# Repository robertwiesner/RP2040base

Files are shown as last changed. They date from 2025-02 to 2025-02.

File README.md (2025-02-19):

A small example for a RP2040 board with I2C (LCD display), LED blinking and some GPIOs

GPIO 0 - 3: LED

J4: 
GPIO6: GPIO/I2C1_SDA
GPIO7: GPIO/I2C1_SCL
GPIO8: GPIO/UART1_TX/I2C0_SDA/SPI1_RX
GPIO9: GPIO/UART1_RX/I2C0_SCL/SPI1_CSn
GPIO10: GPIO/I2C1_SDA/SPI1_SCK
GPIO11: GPIO/I2C1_SCL/SPI1_TX
GPIO12: GPIO/UART0_TX/I2C0_SDA/SPI1_RX
GPIO13: GPIO/UART0_RX/I2C0_SCL/SPI1_CSn

J3:
I2C0, GND, and 3.3V

HTTP Links and cloning:
* https://github.com/raspberrypi/picotool
* https://github.com/raspberrypi/pico-sdk
* https://github.com/raspberrypi/pico-extras

| End Symb |  |
| --- | --- |
| PICO_SDK_PATH | point to <path>/pico-sdk |
| PICO_EXTRAS_PATH | point to <path>/pico-extras |

Clone the pico repositories:
* https://github.com/raspberrypi/pico-sdk.git
* https://github.com/raspberrypi/pico-extras.git
* Install the picotool repository

How to build:
* First time:
 * make build directory in the source directory: mkdir build
 * chdir build
 * cmake ..
* every time
 * Change into build directory
 * Start build using "make"
 * install to pico: picotool load test.uf2 && picotool reboot

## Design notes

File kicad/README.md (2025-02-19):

This directory conteains the schematics and layout data for the C example program.

About the board:
1. Using a USB type C connector for power and USB 2.0 connection
2. I2C connector for LEC display
3. 4 * ANALOG input with 1:10 power divider for the RP2040 ADC input
4. Accessible GPIO 6 - 13
5. 2*5V (USB) and 2*3.3V connector
6. GPIO 0-3 connected to LED
7. 10-pin, 1.27mm SWD connector

The Part numbers in the schemetaics match the JLCPCB (not sponsered) order code.

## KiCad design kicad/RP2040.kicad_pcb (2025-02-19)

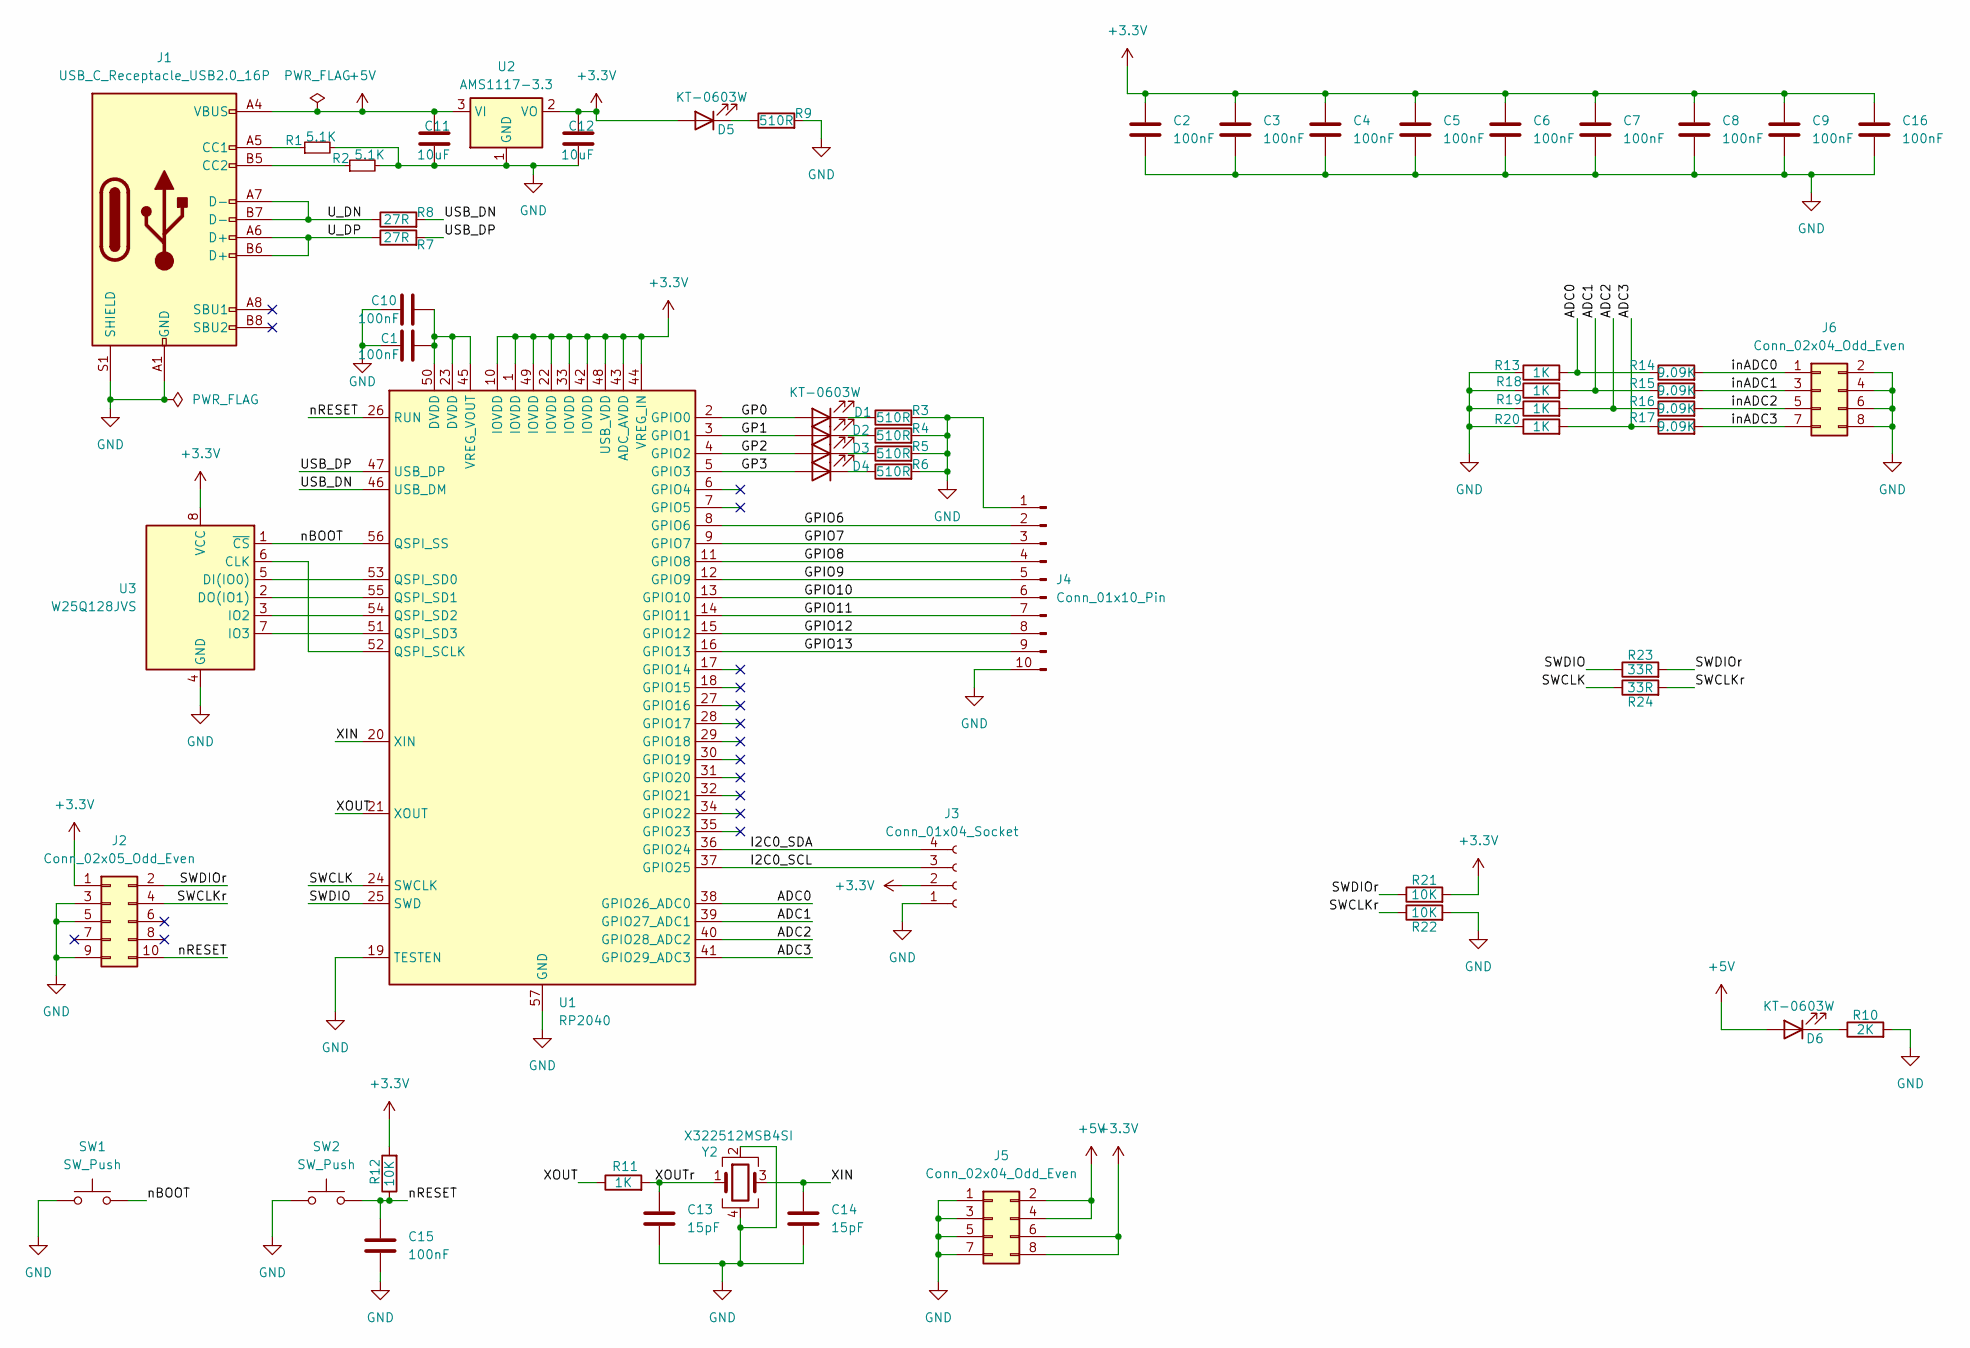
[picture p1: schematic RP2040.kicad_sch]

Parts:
C1, C2, C3, C4, C5, C6, C7, C8, C9, C10, C15, C16: 100nF; C_0402_1005Metric
C11, C12: 10uF; C_0603_1608Metric; LCSC C19702
C13, C14: 15pF; C_0402_1005Metric
D1, D2, D3, D4, D5, D6: KT-0603W; LED_0603_1608Metric
J1: USB_C_Receptacle_USB2.0_16P; USB_C_Receptacle_G-Switch_GT-USB-7010ASV
J2: Conn_02x05_Odd_Even; PinHeader_2x05_P1.27mm_Vertical_SMD; LCSC C5160761
J3: Conn_01x04_Socket; PinSocket_1x04_P2.54mm_Vertical
J4: Conn_01x10_Pin; PinSocket_1x10_P2.54mm_Vertical
J5, J6: Conn_02x04_Odd_Even; PinHeader_2x04_P2.54mm_Vertical
R1, R2: 5.1K; R_0402_1005Metric
R3, R4, R5, R6, R9: 510R; R_0402_1005Metric
R7, R8: 27R; R_0402_1005Metric
R10: 2K; R_0402_1005Metric
R11, R13, R18, R19, R20: 1K; R_0402_1005Metric
R12, R21, R22: 10K; R_0402_1005Metric
R14, R15, R16, R17: 9.09K; R_0402_1005Metric
R23, R24: 33R; R_0402_1005Metric
SW1, SW2: SW_Push; SW_Push_1P1T_XKB_TS-1187A
U1: RP2040; QFN-56-1EP_7x7mm_P0.4mm_EP3.2x3.2mm_ThermalVias
U2: AMS1117-3.3; SOT-223
U3: W25Q128JVS; SOIC-8_5.23x5.23mm_P1.27mm; LCSC C97521
Y2: X322512MSB4SI; Crystal_SMD_3225-4Pin_3.2x2.5mm; LCSC C9002

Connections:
+3.3V: C2.1, C3.1, C4.1, C5.1, C6.1, C7.1, C8.1, C9.1, C12.1, C16.1, D5.2 (A), J2.1, J3.2, J5.6, J5.8, R12.2, R21.2, U1.1 (IOVDD), U1.10 (IOVDD), U1.22 (IOVDD), U1.33 (IOVDD), U1.42 (IOVDD), U1.43 (ADC_AVDD), U1.44 (VREG_IN), U1.48 (USB_VDD), U1.49 (IOVDD), U2.2 (VO), U3.8 (VCC)
+5V: C11.1, D6.2 (A), J1.A4 (VBUS), J1.A9 (VBUS), J1.B4 (VBUS), J1.B9 (VBUS), J5.2, J5.4, U2.3 (VI)
/ADC0: R13.2, R14.1, U1.38 (GPIO26_ADC0)
/ADC1: R15.1, R18.2, U1.39 (GPIO27_ADC1)
/ADC2: R16.1, R19.2, U1.40 (GPIO28_ADC2)
/ADC3: R17.1, R20.2, U1.41 (GPIO29_ADC3)
/GP0: D1.2 (A), U1.2 (GPIO0)
/GP1: D2.2 (A), U1.3 (GPIO1)
/GP2: D3.2 (A), U1.4 (GPIO2)
/GP3: D4.2 (A), U1.5 (GPIO3)
/GPIO6: J4.2, U1.8 (GPIO6)
/GPIO7: J4.3, U1.9 (GPIO7)
/GPIO8: J4.4, U1.11 (GPIO8)
/GPIO9: J4.5, U1.12 (GPIO9)
/GPIO10: J4.6, U1.13 (GPIO10)
/GPIO11: J4.7, U1.14 (GPIO11)
/GPIO12: J4.8, U1.15 (GPIO12)
/GPIO13: J4.9, U1.16 (GPIO13)
/I2C0_SCL: J3.3, U1.37 (GPIO25)
/I2C0_SDA: J3.4, U1.36 (GPIO24)
/SWCLK: R24.1, U1.24 (SWCLK)
/SWCLKr: J2.4, R22.1, R24.2
/SWDIO: R23.1, U1.25 (SWD)
/SWDIOr: J2.2, R21.1, R23.2
/USB_DN: R8.2, U1.46 (USB_DM)
/USB_DP: R7.2, U1.47 (USB_DP)
/U_DN: J1.A7 (D-), J1.B7 (D-), R8.1
/U_DP: J1.A6 (D+), J1.B6 (D+), R7.1
/XIN: C14.1, U1.20 (XIN), Y2.3
/XOUT: R11.1, U1.21 (XOUT)
/XOUTr: C13.1, R11.2, Y2.1
/inADC0: J6.1, R14.2
/inADC1: J6.3, R15.2
/inADC2: J6.5, R16.2
/inADC3: J6.7, R17.2
/nBOOT: SW1.2, U1.56 (QSPI_SS), U3.1 (~CS)
/nRESET: C15.1, J2.10, R12.1, SW2.2, U1.26 (RUN)
GND: C1.2, C2.2, C3.2, C4.2, C5.2, C6.2, C7.2, C8.2, C9.2, C10.2, C11.2, C12.2, C13.2, C14.2, C15.2, C16.2, J1.A1 (GND), J1.A12 (GND), J1.B1 (GND), J1.B12 (GND), J1.S1 (SHIELD), J2.3, J2.5, J2.9, J3.1, J4.1, J4.10, J5.1, J5.3, J5.5, J5.7, J6.2, J6.4, J6.6, J6.8, R1.2, R2.2, R3.2, R4.2, R5.2, R6.2, R9.2, R10.2, R13.1, R18.1, R19.1, R20.1, R22.2, SW1.1, SW2.1, U1.19 (TESTEN), U1.57 (GND), U2.1 (GND), U3.4 (GND), Y2.2, Y2.4
unnamed: D1.1 (K), R3.1
unnamed: D2.1 (K), R4.1
unnamed: D3.1 (K), R5.1
unnamed: D4.1 (K), R6.1
unnamed: D5.1 (K), R9.1
unnamed: D6.1 (K), R10.1
unnamed: J1.A5 (CC1), R1.1
unnamed: J1.B5 (CC2), R2.1
unnamed: U1.52 (QSPI_SCLK), U3.6 (CLK)
unnamed: U1.53 (QSPI_SD0), U3.5 (DI(IO0))
unnamed: U1.55 (QSPI_SD1), U3.2 (DO(IO1))
unnamed: U1.54 (QSPI_SD2), U3.3 (IO2)
unnamed: U1.51 (QSPI_SD3), U3.7 (IO3)
unnamed: C1.1, C10.1, U1.23 (DVDD), U1.45 (VREG_VOUT), U1.50 (DVDD)

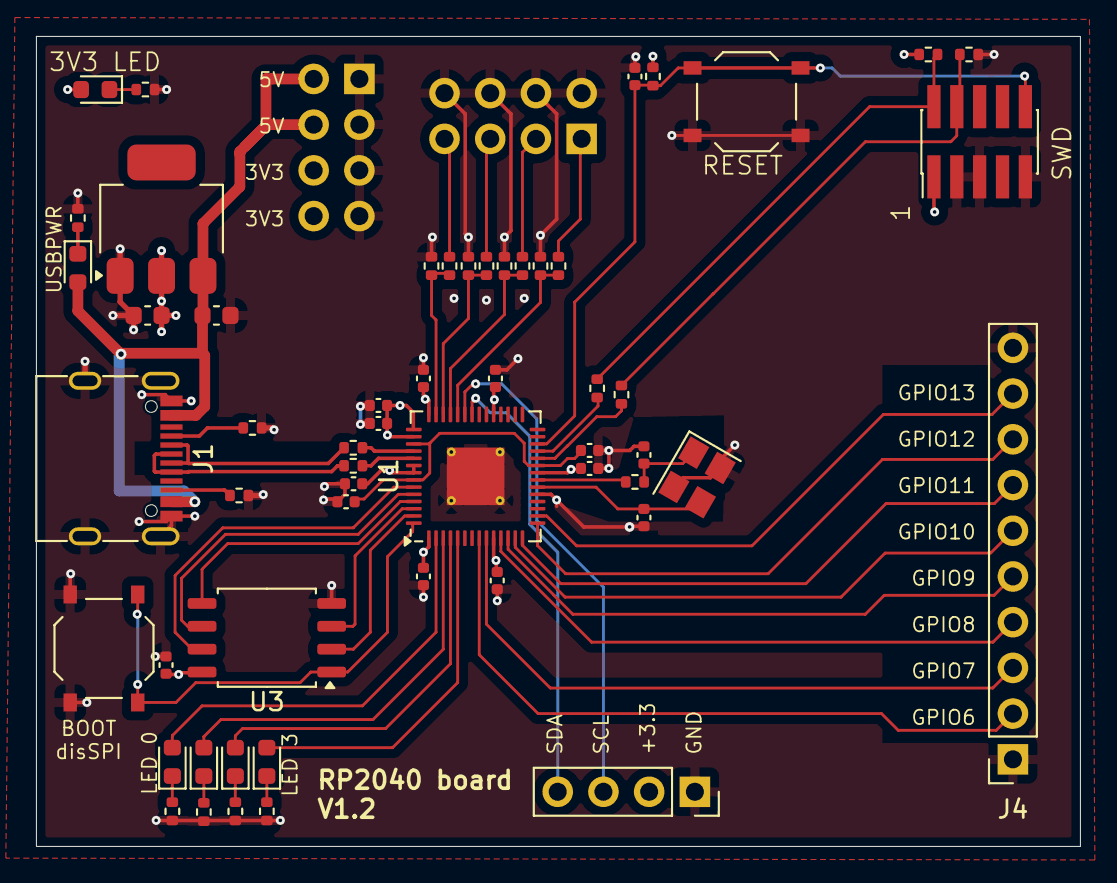
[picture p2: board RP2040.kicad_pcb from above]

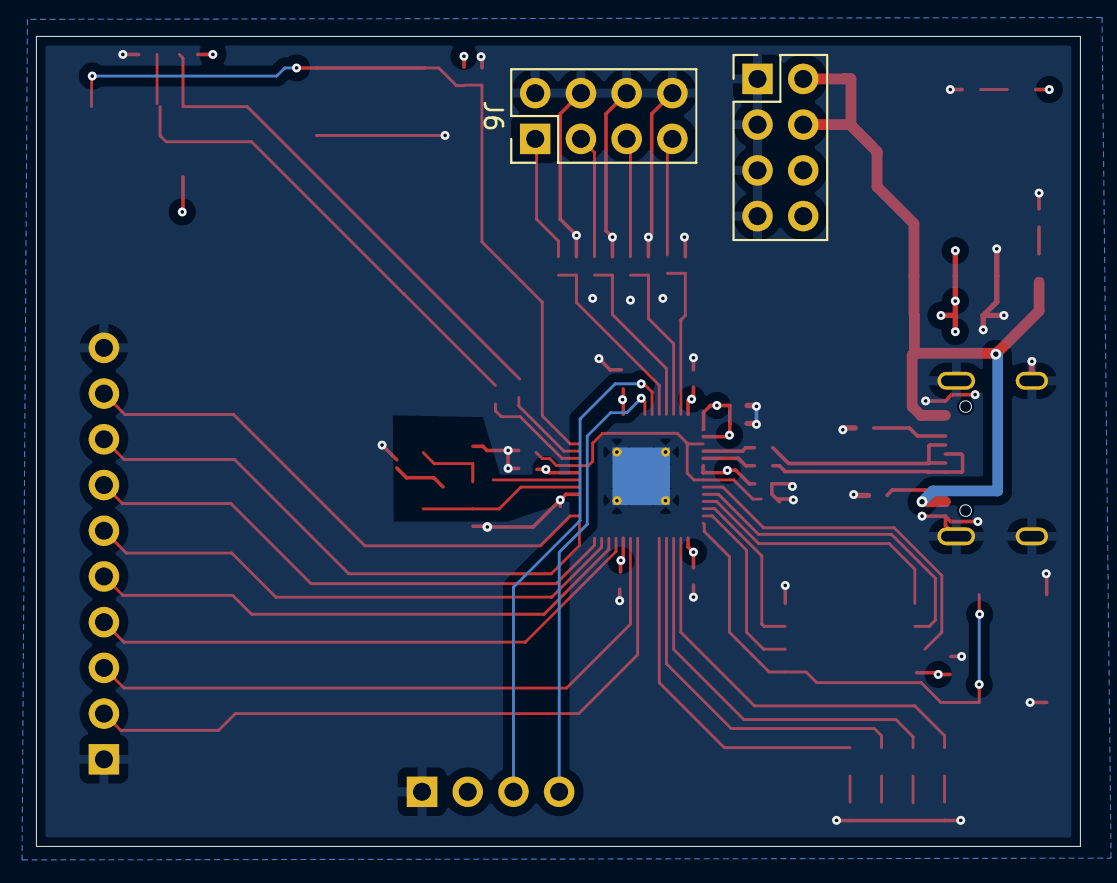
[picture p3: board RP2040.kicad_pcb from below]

Board: 4 copper layers, 58.0 x 45.0 mm, 58 parts (2 on the bottom side), 52 nets.

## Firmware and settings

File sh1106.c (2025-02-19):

#include "hardware/gpio.h"
#include "hardware/i2c.h"
#include "pico/binary_info.h"


#include "sh1106.h"

#define I2C1 0

#if I2C1
#define I2C i2c1
#define I2C1_SDA_PIN 18
#define I2C1_SCL_PIN 19
#else
#define I2C i2c0
#define I2C0_SDA_PIN 24
#define I2C0_SCL_PIN 25
#endif
#define ADDR 0x3c
#define MAXY LCD_MAX_Y
#define MAXX LCD_MAX_X

#define LOW_COLUMN_ADDRESS  (0x00)
#define HIGH_COLUMN_ADDRESS (0x10)
#define SET_MEMORY_MODE     (0x20)
#define SET_START_LINE      (0x40)
#define SET_CONTRAST        (0x81)
#define SET_CHARGE_PUMP     (0x8D)
#define SET_SEG_REMAP       (0xA0)
#define SET_DISPLAY_RESUME  (0xA4)
#define SET_NORM_INV        (0xA6)
#define SET_MULTIPLEX       (0xA8)
#define SET_DISP            (0xAE)
#define SET_SCAN_DIR        (0xC0)
#define SET_PAGE_ADDRESS    (0xB0)
#define SET_COM_PINS        (0xDA)
#define SET_DISP_OFFSET     (0xD3)
#define SET_CLOCK_DIV       (0xD5)
#define SET_PRECHARGE       (0xD9)
#define SET_VCOM_DETECT     (0xDB)

typedef struct sCoord {
	int x, y;
} tCoord;

tLCD LCD_lcd;

static void
writeToLCD(int len, char *pBuffer)
{
	i2c_write_blocking(I2C, ADDR, pBuffer, len, false);
}

static void
writeCommand(int cmd)
{
    char aBuffer[2] = {0x00, cmd};

    writeToLCD(2, aBuffer);
}

void
LCD_update()
{
	for (int y = 0; y < MAXY/8; y++) {
		if (LCD_lcd.aaBuffer[y][0]) {
			LCD_lcd.aaBuffer[y][0] = 0;
			writeCommand(LOW_COLUMN_ADDRESS  | 0);
			writeCommand(HIGH_COLUMN_ADDRESS | 0);
			writeCommand(SET_PAGE_ADDRESS + y);
    			writeToLCD(MAXX+3, LCD_lcd.aaBuffer[y]+1);
		}
	}
}

void
my_memset(int *pPtr, int size)
{
	while(0 < size) {
		*pPtr++ = 0;
		size -= 4;
	}
}

void
LCD_init()
{

	i2c_init(I2C, 400 * 1000);
#if I2C1
	gpio_set_function(I2C1_SDA_PIN, GPIO_FUNC_I2C);
	gpio_set_function(I2C1_SCL_PIN, GPIO_FUNC_I2C);
    	bi_decl(bi_2pins_with_func(I2C1_SDA_PIN, I2C1_SCL_PIN, GPIO_FUNC_I2C));
#else
	gpio_set_function(I2C0_SDA_PIN, GPIO_FUNC_I2C);
	gpio_set_function(I2C0_SCL_PIN, GPIO_FUNC_I2C);
    	bi_decl(bi_2pins_with_func(I2C0_SDA_PIN, I2C0_SCL_PIN, GPIO_FUNC_I2C));
#endif
	for (int y = 0; y < MAXY/8; y++) {
		LCD_lcd.aaBuffer[y][0] = 1;
		LCD_lcd.aaBuffer[y][1] = 0x40;
		LCD_lcd.aaBuffer[y][2] = 0;
		LCD_lcd.aaBuffer[y][3] = 0;
		for (int x = 0; x < MAXX; x++) {
			LCD_lcd.aaBuffer[y][4+x] = 0;
		}
	}
	
	writeCommand(SET_DISP | 0);

	writeCommand(SET_CLOCK_DIV);
	writeCommand(0x80);

	writeCommand(SET_MULTIPLEX);
	writeCommand(64-1);

	writeCommand(SET_DISP_OFFSET);
	writeCommand(0);

	writeCommand(SET_START_LINE);
	writeCommand(SET_CHARGE_PUMP);

	writeCommand(0x14); // or 0x10?

	writeCommand(SET_MEMORY_MODE);
	writeCommand(0x00);

	writeCommand(SET_SEG_REMAP | 1);

	writeCommand(SET_SCAN_DIR | 8);

	writeCommand(SET_COM_PINS);
	writeCommand(0x12);

	writeCommand(SET_CONTRAST);
	writeCommand(0x8f);

	writeCommand(SET_PRECHARGE);

	writeCommand(0xF1); // or 0x22?

	writeCommand(SET_VCOM_DETECT);
	writeCommand(0x40);

	writeCommand(SET_DISPLAY_RESUME);
	writeCommand(SET_NORM_INV);
	writeCommand(SET_DISP | 1);

	LCD_update();
}

void
LCD_hline(int sx, int sy, int ex)
{
	int y = sy / 8;
	int bit = 0x1 << (sy & 7);
	LCD_lcd.aaBuffer[y][0] = 1;

	unsigned char *pDst = LCD_lcd.aaBuffer[y] + 4;	
	while (sx <= ex) {
		pDst[sx++] |= bit;
	}
}

void
LCD_vline(int sx, int sy, int ey)
{
	int y = sy / 8;
	int ye = ey / 8;
	int bits = 0xff << (sy & 7);

	unsigned char *pDst = LCD_lcd.aaBuffer[y] + 4;	

	for (y = sy / 8; y < ye; y++) {
		pDst[-4] = 1;
		pDst[sx] |= bits;
		bits = 0xff;
		pDst += sizeof(LCD_lcd.aaBuffer[0]); 
	}

	pDst[-4] = 1;
	// deal with the last line
	if (ey & 7) {
		bits &= 0xff >> (7 - (ey & 7));
	}
	pDst[sx] |= bits;
}

void
LCD_rect_set(int sx, int sy, int ex, int ey)
{
	int y;
	int ye = ey / 8;
	int bits = 0xff << (sy & 7);

	unsigned char *pDst = LCD_lcd.aaBuffer[y] + 4;

	for (y = sy / 8; y < ye; y++) {
		pDst[-4] = 1;
		for (int x = sx; x <= ex; x++) {
			pDst[x] |= bits;
		}
		bits = 0xff;
		pDst += sizeof(LCD_lcd.aaBuffer[0]); 
	}

	pDst[-4] = 1;
	// deal with the last line
	if (ey & 7) {
		bits &= 0xff >> (7 - (ey & 7));
	}

	for (int x = sx; x <= ex; x++) {
		pDst[x] |= bits;
	}
}

void
LCD_rect_inv(int sx, int sy, int ex, int ey)
{
	int y;
	int ye = ey / 8;
	int bits = 0xff << (sy & 7);

	unsigned char *pDst = LCD_lcd.aaBuffer[y] + 4;

	for (y = sy / 8; y < ye; y++) {
		pDst[-4] = 1;
		for (int x = sx; x <= ex; x++) {
			pDst[x] ^= bits;
		}
		bits = 0xff;
		pDst += sizeof(LCD_lcd.aaBuffer[0]); 
	}

	pDst[-4] = 1;
	// deal with the last line
	if (ey & 7) {
		bits &= 0xff >> (7 - (ey & 7));
	}

	for (int x = sx; x <= ex; x++) {
		pDst[x] ^= bits;
	}
}

void
LCD_rect_clr(int sx, int sy, int ex, int ey)
{
	int y;
	int ye = ey / 8;
	int bits = ~(0xff << (sy & 7));

	unsigned char *pDst = LCD_lcd.aaBuffer[y] + 4;

	for (y = sy / 8; y < ye; y++) {
		pDst[-4] = 1;
		for (int x = sx; x <= ex; x++) {
			pDst[x] &= bits;
		}
		bits = 0x00;
		pDst += sizeof(LCD_lcd.aaBuffer[0]); 
	}

	pDst[-4] = 1;
	// deal with the last line
	if (ey & 7) {
		bits &= ~(0xff >> (7 - (ey & 7)));
	}

	for (int x = sx; x <= ex; x++) {
		pDst[x] &= bits;
	}
}

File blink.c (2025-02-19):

#include <stdio.h>
#include "pico/stdlib.h"
#include "hardware/gpio.h"
#include "hardware/adc.h"
#include "pico/binary_info.h"

#include "sh1106.h"
const uint LED_PIN = 0;

int main()
{

    int cnt = 0;

    adc_init();
    adc_gpio_init(38);
    adc_gpio_init(39);
    adc_gpio_init(40);
    adc_gpio_init(41);

    LCD_init();

    LCD_text(0, 0, "Hello World!!!");
    LCD_update();

    for (int i = 0; i < 4; i++) {
    	gpio_init(i);
    	gpio_set_dir(i, GPIO_OUT);
    }

    while (1) {
	cnt++;
    	for (int i = 0; i < 4; i++) {
            gpio_put(i, (cnt & (1 << i)) ? 1 : 0 );
	}
	
    	for (int i = 0; i < 4; i++) {
	    int val;
	    adc_select_input(0);
	    val = adc_read();

	    int x = LCD_number(0, 8+8*i, 1, 10, i);
    	    x = LCD_text(x, 8+8*i, ". ADC: ");
	    x = LCD_number(0, 8+8*i, 4, 10, val);
    	    x = LCD_text(x, 8+8*i, " mV");
	}
	LCD_number(0, 8*6, 8, 10, cnt);
        LCD_update();

        sleep_ms(250);
    }
}

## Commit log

2025-02-19 Add files via upload
    Initial commit.
    [RP2040.kicad_pcb, RP2040.kicad_sch]
2025-02-19 Update README.md
    Add PCB description
